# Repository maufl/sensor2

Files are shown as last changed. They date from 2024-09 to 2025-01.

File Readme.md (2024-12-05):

# A ESP based sensor platform
This is a learning project for me. The goal is to build sensors (and maybe eventually actors) using ESP32 micro-controllers that can run on battery for a long time (a year and more).
I started it to learn PCB design and embedded programming.

## Climate sensor
The hardware design for the climate sensor does work now the way I hoped. 
Most of all this means that the linear voltage regulator provides enough power even when sending data over WiFi or BLE 
and that I can put the ESP into deep sleep and the whole board will only consume around 11µA.

Software wise I do have a firmware written in Rust that periodically sends measurements via BLE using the [BTHome](https://bthome.io/) standard and goes into deep sleep during the rest of the time.

Using an small LiPo battery with 700mAh it should last at least a year.

There is an (even more) experimental feature of doing the measurements using the low power core that is not working yet. 
The idea would be to measure with a higher frequency than send measurements with a lower frequency, thus saving power.

## License
All hardware is licensed under CERN OHL S 2.0 and all software is licensed under GNU GPLv3.

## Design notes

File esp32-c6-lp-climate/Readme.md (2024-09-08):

# Low power climate sensor
This is a minimal program to run on the ESP32-C6 LP core and read a Bosch BME280 sensor.
It's based on the [I2C example from the esp-lp-hal crate](https://github.com/esp-rs/esp-hal/blob/main/esp-lp-hal/examples/i2c.rs).

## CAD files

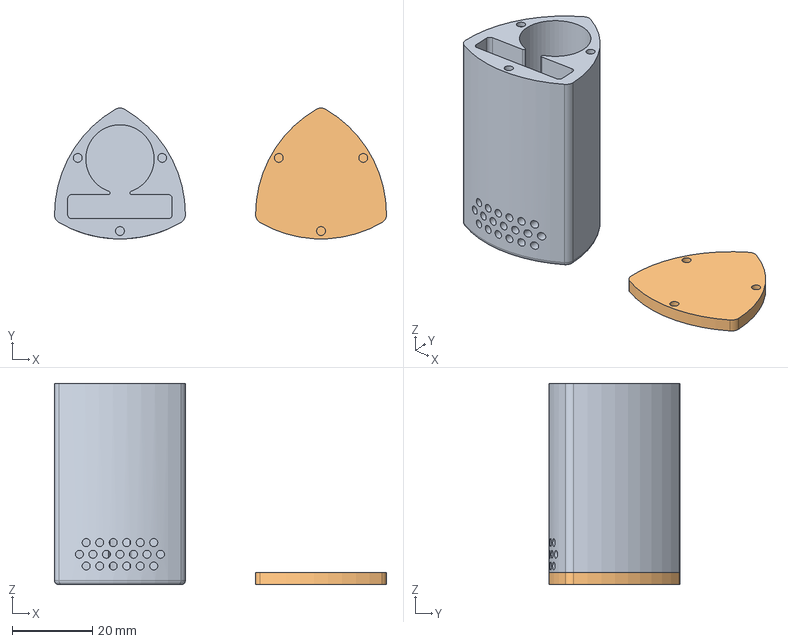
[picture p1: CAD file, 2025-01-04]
hardware/temperature_sensor/housing.FCStd
82.6 x 32.6 x 50.0 mm
Lid

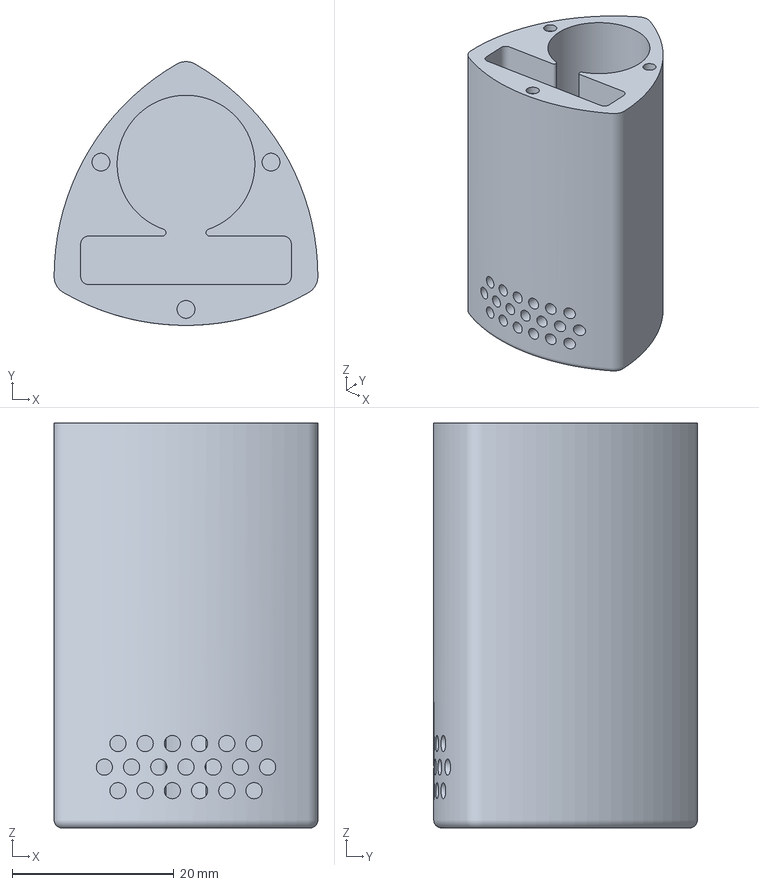
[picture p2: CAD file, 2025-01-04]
hardware/temperature_sensor/housing-body.3mf
32.6 x 32.6 x 50.0 mm

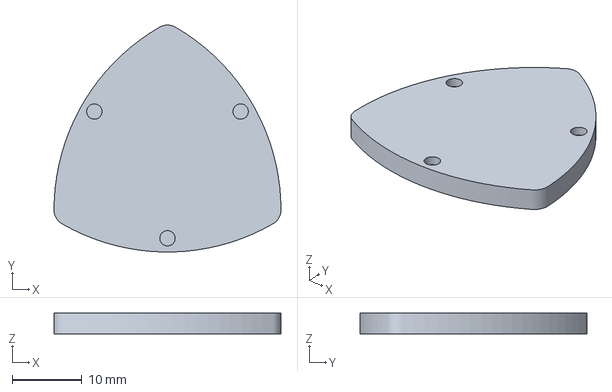
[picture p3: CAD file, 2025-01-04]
hardware/temperature_sensor/housing-lid.3mf
32.6 x 32.6 x 3.00 mm

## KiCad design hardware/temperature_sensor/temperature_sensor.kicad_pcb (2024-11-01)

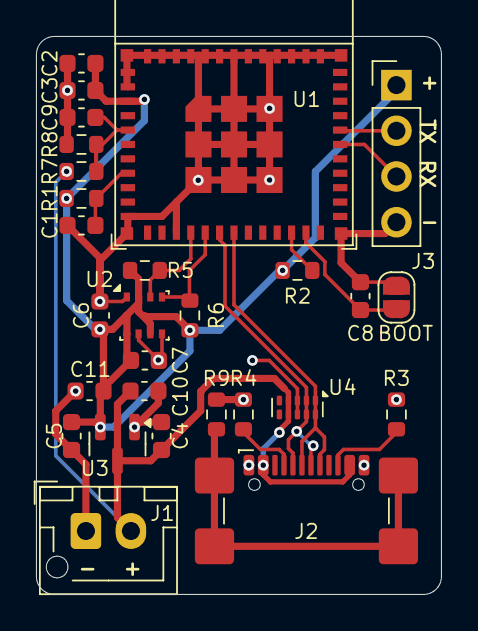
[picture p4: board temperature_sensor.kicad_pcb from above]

Board: 2 copper layers, 22.5 x 31.0 mm, 28 parts (0 on the bottom side), 16 nets.

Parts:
BOOT: SolderJumper_2_Open; SolderJumper-2_P1.3mm_Open_RoundedPad1.0x1.5mm
C1: 1µF; C_0603_1608Metric
C2, C8, C9: 100nF; C_0603_1608Metric
C3: 10µF; C_0603_1608Metric
C4, C5: 1 µF; C_0603_1608Metric
C6, C7: 100 nF; C_0603_1608Metric
C10, C11: 47µF; C_0603_1608Metric
J1: Conn_01x02_Male; JST_XH_B2B-XH-AM_1x02_P2.50mm_Vertical
J2: USB_C_Receptacle_USB2.0_16P; USB_C_Receptacle_GCT_USB4110
J3: Conn_01x04_Socket; PinHeader_1x04_P2.54mm_Vertical
R1: 10K 1%; R_0603_1608Metric
R2: 3.3K 1%; R_0603_1608Metric
R3, R4: 5.1K; R_0603_1608Metric
R5, R6: 4.7 k; R_0603_1608Metric
R7: 4,7 M; R_0603_1608Metric
R8: 1 M; R_0603_1608Metric
R9: 1M; R_0603_1608Metric
U1: ESP32-C6-MINI-1/U; ESP32-C6-MINI-1
U2: BME280; Bosch_LGA-8_2.5x2.5mm_P0.65mm_ClockwisePinNumbering
U3: MCP1700x-330xxTT; SOT-23
U4: TPD4E02B04DQA; USON-10_2.5x1.0mm_P0.5mm

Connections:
+3.3V: C2.1, C3.1, C5.1, C6.1, C7.1, C11.1, J3.1, R1.1, R2.2, R5.1, R6.1, U1.3 (3V3), U2.2 (CSB), U2.6 (VDDIO), U2.8 (VDD), U3.2 (VO)
+BATT: C4.1, C10.1, J1.2, J2.A4 (VBUS), J2.A9 (VBUS), J2.B4 (VBUS), J2.B9 (VBUS), R7.1, U3.3 (VI), U4.4 (IO3), U4.7 (NC)
/ADC: C9.2, R7.2, R8.1, U1.5 (GPIO2/ADC1_CH2)
/BOOT_MODE: BOOT.1 (A), C8.2, U1.23 (GPIO9)
/EN: C1.2, R1.2, U1.8 (EN/CHIP_PU)
/I2C_SCL: R6.2, U1.16 (MTDO/GPIO7), U2.4 (SCK)
/I2C_SDA: R5.2, U1.15 (MTCK/GPIO6/ADC1_CH6), U2.3 (SDI)
/U0RXD: J3.3, U1.30 (U0RXD/GPIO17)
/U0TXD: J3.2, U1.31 (U0TXD/GPIO16)
/USB_D+: J2.A6 (D+), J2.B6 (D+), U1.18 (GPIO13/USB_D+), U4.1 (IO1), U4.10 (NC)
/USB_D-: J2.A7 (D-), J2.B7 (D-), U1.17 (GPIO12/USB_D-), U4.2 (IO2), U4.9 (NC)
GND: BOOT.2 (B), C1.1, C2.2, C3.2, C4.2, C5.2, C6.2, C7.2, C8.1, C9.1, C10.2, C11.2, J1.1, J2.A1 (GND), J2.A12 (GND), J2.B1 (GND), J2.B12 (GND), J3.4, R3.2, R4.2, R8.2, R9.2, U1.1 (GND), U1.2 (GND), U1.11 (GND), U1.14 (GND), U1.36 (GND), U1.37 (GND), U1.38 (GND), U1.39 (GND), U1.40 (GND), U1.41 (GND), U1.42 (GND), U1.43 (GND), U1.44 (GND), U1.45 (GND), U1.46 (GND), U1.47 (GND), U1.48 (GND), U1.49 (GND), U1.50 (GND), U1.51 (GND), U1.52 (GND), U1.53 (GND), U2.1 (GND), U2.5 (SDO), U2.7 (GND), U3.1 (GND), U4.3 (G), U4.8 (G)
unnamed: J2.A5 (CC1), R4.1
unnamed: J2.B5 (CC2), R3.1
unnamed: J2.S1 (SHIELD), R9.1
unnamed: R2.1, U1.22 (GPIO8)

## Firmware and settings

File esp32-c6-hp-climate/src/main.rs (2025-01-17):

#![no_std]
#![no_main]

use defmt_rtt as _;

use core::time::Duration;

use bleps::{
    ad_structure::{
        create_advertising_data, AdStructure, BR_EDR_NOT_SUPPORTED, LE_GENERAL_DISCOVERABLE,
    },
    Ble, HciConnector,
};
use bme280::i2c::BME280;
use esp_backtrace as _;
use esp_hal::{
    analog::adc::{Adc, AdcConfig, Attenuation}, clock::CpuClock, delay::Delay, gpio::{lp_io::LowPowerOutputOpenDrain, GpioPin}, i2c::{
        lp_i2c::LpI2c,
        master::{Config, I2c},
    }, load_lp_code, lp_core::{LpCore, LpCoreWakeupSource}, main, peripherals::{Peripherals, ADC1, BT, I2C0, LPWR, LP_CORE, LP_I2C0}, reset::{wakeup_cause, SleepSource}, rng::Rng, rtc_cntl::{
        sleep::{TimerWakeupSource, WakeFromLpCoreWakeupSource},
        Rtc,
    }, time::RateExtU32, timer::timg::TimerGroup
};
use esp_wifi::{ble::controller::BleConnector, EspWifiController};

use shared::{Measurement, MeasurmentBuffer, SHARED_MEMORY_ADDRESS};

const DEEP_SLEEP_SECONDS: u64 = 10 * 60;
const U12_MAX: u16 = (1 << 12) - 1;

#[main]
fn main() -> ! {
    defmt::info!("Starting up");

    let mut config = esp_hal::Config::default().with_cpu_clock(CpuClock::_80MHz);
    let peripherals = esp_hal::init(config);

    defmt::info!("Allocating heap");

    esp_alloc::heap_allocator!(144 * 1024);

    let Peripherals {
        LPWR,
        LP_CORE,
        I2C0,
        LP_I2C0,
        ADC1,
        GPIO2,
        GPIO6,
        GPIO7,
        TIMG0,
        RNG,
        RADIO_CLK,
        BT,
        ..
    } = peripherals;

    let battery_charge = read_battery_charge(GPIO2, ADC1);

    let measurement = if cfg!(feature = "lp") {
        if let SleepSource::Ulp = wakeup_cause() {
            read_lp_measurement()
        } else {
            start_lp_core(GPIO6, GPIO7, LP_I2C0, LP_CORE);
            sleep_wake_lp_core(LPWR);
        }
    } else {
        defmt::debug!("Disabling LP core");
        LpCore::new(LP_CORE).stop();
        measure_climate(I2C0, GPIO6, GPIO7).expect("measurement to succeed")
    };

    defmt::debug!("Starting setup of Bluetooth stack");
    let timg0 = TimerGroup::new(TIMG0);
    defmt::debug!("Initializing Wifi controller");
    let wifi_controller = match esp_wifi::init(timg0.timer0, Rng::new(RNG), RADIO_CLK) {
        Ok(v) => v,
        Err(err) => {
            defmt::error!("Failed to initialize wifi: {}", err);
            loop {}
        }
    };

    sent_ble_advertisments(&wifi_controller, BT, &measurement, battery_charge);

    if let Err(err) = wifi_controller.deinit() {
        defmt::debug!("Error deinitializing wifi controller {:?}", err);
    }

    if cfg!(feature = "lp") {
        sleep_wake_lp_core(LPWR);
    } else {
        sleep_wake_timer(LPWR);
    }
}

type AdcCal = esp_hal::analog::adc::AdcCalBasic<esp_hal::peripherals::ADC1>;

fn read_battery_charge(analog_pin: GpioPin<2>, adc: ADC1) -> f32 {
    let mut adc1_config = AdcConfig::new();
    // At an attenuation of 2.5 dB the input voltage range that can be read is ~100mV-1250mV
    // The board contains an additional voltage devider with 1 MO - 4.7 MO
    // u12::max == 1250mV -> bat / u12::max * 1.25 * 5.7 ??
    let mut pin =
        adc1_config.enable_pin_with_cal::<_, AdcCal>(analog_pin, Attenuation::_2p5dB);
    let mut adc1 = Adc::new(adc, adc1_config);
    let bat = adc1.read_oneshot(&mut pin).unwrap();
    (bat as f32 / U12_MAX as f32) * 7.125
}

fn sent_ble_single_advertisment(
    ble: &mut Ble,
    measurement: &Measurement,
    battery_charge: f32,
) {
    let [t0, t1] = ((measurement.temperature * 100.0) as u16).to_le_bytes();
    let [h0, h1] = ((measurement.humidity * 100.0) as u16).to_le_bytes();
    // pressure doesn't have to be scaled since it's already in Pascal
    let [p0, p1, p2, _] = ((measurement.pressure) as u32).to_le_bytes();
    let [b0, b1] = ((battery_charge * 1000.0) as u16).to_le_bytes();
    let _ = ble.cmd_set_le_advertising_data(
        create_advertising_data(&[
            AdStructure::Flags(LE_GENERAL_DISCOVERABLE | BR_EDR_NOT_SUPPORTED),
            AdStructure::ServiceData16 {
                uuid: 0xFCD2,
                data: &[
                    0x40, 0x02, t0, t1, 0x03, h0, h1, 0x04, p0, p1, p2, 0x0C, b0, b1,
                ],
            },
            AdStructure::CompleteLocalName("esp32"),
        ])
        .unwrap(),
    );
    let _ = ble.cmd_set_le_advertise_enable(true);
}

fn measure_climate(
    i2c0: I2C0,
    gpio06: GpioPin<6>,
    gpio07: GpioPin<7>,
) -> Result<Measurement, bme280::Error<esp_hal::i2c::master::Error>> {
    let mut delay = Delay::new();
    let i2c = I2c::new(
        i2c0,
        Config::default().with_frequency(100_u32.kHz())
    ).unwrap()
    .with_sda(gpio06)
    .with_scl(gpio07);

    let mut bme280 = BME280::new_primary(i2c);
    defmt::debug!("Initializing sensor");
    bme280.init(&mut delay)?;
    bme280.measure(&mut delay).map(|m| Measurement {
        temperature: m.temperature,
        humidity: m.humidity,
        pressure: m.pressure,
        error: None,
    })
}

fn sleep_wake_timer(lpwr: LPWR) -> ! {
    let mut rtc = Rtc::new(lpwr);
    let timer = TimerWakeupSource::new(Duration::from_secs(DEEP_SLEEP_SECONDS));
    defmt::debug!("sleeping!");
    rtc.sleep_deep(&[&timer]);
}

fn sleep_wake_lp_core(lpwr: LPWR) -> ! {
    let mut rtc = Rtc::new(lpwr);
    let waker = WakeFromLpCoreWakeupSource::new();
    defmt::debug!("sleeping!");
    rtc.sleep_deep(&[&waker]);
}

fn sent_ble_advertisments<'d>(
    wifi_controller: &EspWifiController<'d>,
    mut bt: BT,
    measurement: &Measurement,
    battery_charge: f32,
) {
    let delay = Delay::new();
    defmt::debug!("Setting up BLE connector");
    let connector = BleConnector::new(&wifi_controller, &mut bt);
    let now = || esp_hal::time::now().duration_since_epoch().to_millis();
    let hci = HciConnector::new(connector, now);
    let mut ble = Ble::new(&hci);
    defmt::debug!("Finished setup of Bluetooth stack, initializing");
    if let Err(err) = ble.init() {
        return defmt::error!("Error initializing BTL stack {}", err);
    }
    let _ = ble.cmd_set_le_advertising_parameters();

    sent_ble_single_advertisment(&mut ble, &measurement, battery_charge);
    delay.delay_millis(100);

    if let Err(e) = ble.cmd_reset() {
        defmt::debug!("Error resetting BLE stack {:?}", e)
    }
}

fn start_lp_core(gpio06: GpioPin<6>, gpio07: GpioPin<7>, lp_i2c: LP_I2C0, lp_core: LP_CORE) {
    let lp_sda = LowPowerOutputOpenDrain::new(gpio06);
    let lp_scl = LowPowerOutputOpenDrain::new(gpio07);

    let lp_i2c = LpI2c::new(lp_i2c, lp_sda, lp_scl, 100_u32.kHz());

    let mut lp_core = LpCore::new(lp_core);

    // load code to LP core
    let lp_core_code = load_lp_code!(
        "../esp32-c6-lp-climate/target/riscv32imac-unknown-none-elf/release/esp32-c6-lp-climate"
    );

    // start LP core
    lp_core_code.run(&mut lp_core, LpCoreWakeupSource::HpCpu, lp_i2c);
    defmt::debug!("Starting LP core");
}

fn read_lp_measurement() -> Measurement {
    let ptr = SHARED_MEMORY_ADDRESS as *mut MeasurmentBuffer;
    let buffer = unsafe { ptr.read_volatile() };
    let last_measurement = (buffer.next_index - 1 % 10) as usize;
    buffer.measurements[last_measurement]
}

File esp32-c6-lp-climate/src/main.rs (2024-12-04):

#![no_std]
#![no_main]

use bme280::i2c::BME280;
use esp_lp_hal::{i2c::LpI2c, prelude::*, wake_hp_core};
use panic_halt as _;
use shared::{Measurement, MeasurmentBuffer, MeasurmentError, SHARED_MEMORY_ADDRESS};

#[derive(Debug, Copy, Clone)]
struct Delay;

impl embedded_hal::blocking::delay::DelayMs<u8> for Delay {
    fn delay_ms(&mut self, ms: u8) {
        esp_lp_hal::delay::Delay {}.delay_ms(ms.into());
    }
}

fn convert_error(value: &bme280::Error<esp_lp_hal::i2c::Error>) -> MeasurmentError {
    match value {
        bme280::Error::CompensationFailed => MeasurmentError::CompensationFailed,
        bme280::Error::Bus(_) => MeasurmentError::BusError,
        bme280::Error::InvalidData => MeasurmentError::InvalidData,
        bme280::Error::NoCalibrationData => MeasurmentError::NoCalibrationData,
        bme280::Error::UnsupportedChip => MeasurmentError::UnsupportedChip,
    }
}

#[entry]
fn main(i2c: LpI2c) -> ! {
    let _peripherals = esp32c6_lp::Peripherals::take().unwrap();
    let mut sensor = BME280::new_primary(i2c, Delay {});
    let delay = esp_lp_hal::delay::Delay {};
    let buffer = unsafe {
        (SHARED_MEMORY_ADDRESS as *mut MeasurmentBuffer)
            .as_mut()
            .unwrap()
    };
    *buffer = MeasurmentBuffer {
        measurements: [Measurement {
            temperature: 0.0,
            pressure: 0.0,
            humidity: 0.0,
            error: None,
        }; 10],
        next_index: 0,
    };

    let initialization_error = sensor.init().err();

    loop {
        let current_measurement = &mut buffer.measurements[buffer.next_index as usize];
        *current_measurement = Measurement {
            temperature: 0.0,
            pressure: 0.0,
            humidity: 0.0,
            error: None,
        };
        if let Some(ref err) = initialization_error {
            current_measurement.error = Some(convert_error(err));
        } else {
            match sensor.measure() {
                Ok(m) => {
                    *current_measurement = Measurement {
                        temperature: m.temperature,
                        pressure: m.pressure,
                        humidity: m.humidity,
                        error: None,
                    }
                }
                Err(err) => current_measurement.error = Some(convert_error(&err)),
            }
        }
        buffer.next_index = buffer.next_index + 1 % 10;
        delay.delay_millis(6 * 1000);
        wake_hp_core();
    }
}

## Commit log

2024-09-29 Add code to read sensor form HP core
2024-09-29 Try debugging with probe-rs
2024-09-29 Add hardware design
    [temperature_sensor.kicad_pcb, temperature_sensor.kicad_sch]
2024-10-31 Update schema and PCB, more caps, antenna hanging free
    [temperature_sensor.kicad_pcb, temperature_sensor.kicad_sch]
2024-11-01 Use grid override for text
    [temperature_sensor.kicad_pcb]
2024-11-24 Add battery charge reading
2024-12-04 Improve the battery voltage reading
2025-01-04 Add housing prototype
    [housing-body.3mf, housing-lid.3mf, housing.FCStd]
